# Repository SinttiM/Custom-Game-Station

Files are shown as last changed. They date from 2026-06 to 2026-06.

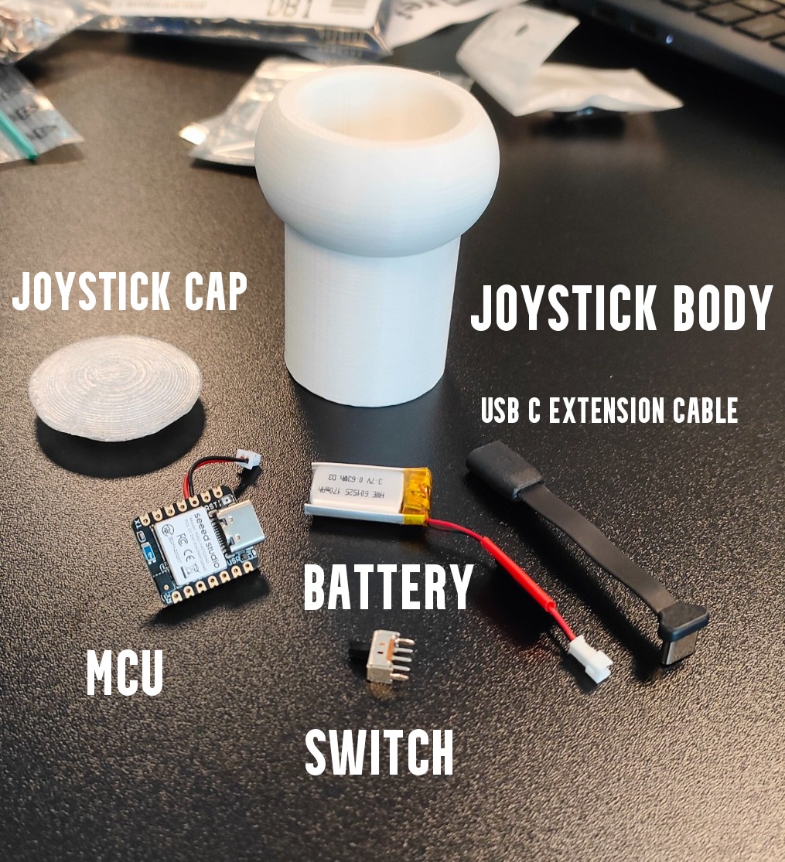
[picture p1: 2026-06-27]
Photos/JoystickComponents.jpg

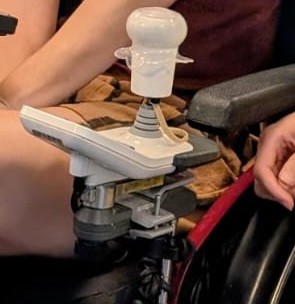
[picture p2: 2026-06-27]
Photos/Final Solution Product Image.jpeg

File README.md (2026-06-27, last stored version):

# Custom-Game-Station

Project results of "ASSIST HEIDI - Designing and implementing Assistive Tools for people with disabilities" course.

A Custom Game Station designed for specifical needs of our co-designer. It is a multifunctional adaptive system projected to replace standard joystick and triggers. Specifically, the user requested a customized system to play "Blue Prince", a game requiring strategic navigation and interaction, but can be adapted to easily play multiple games.

## Product overview

This solution is composed of 1 Puck.js microcontroller (in Joystick), which could be easily connected wirelessly to a PC through Web Bluetooth. Connected to this, 2 switch buttons (T: Top Button, S: Side Button) and a custom 3D printed support. The solution is meant to be applied on a wheelchair.

   
  

## Key Features

### Wheelchair Joystick

* Could work both as **PC mouse** or **WASD keys** on keyboard, it depends on the selected modality
* Could be recalibrated every time needed
* Adjustable Sensitivity: Settings to adjust joystick sensitivity to individual needs.

### Top Cover

* Holds the batteries Battery Pack (B) for the Puck.js
* Hosts the Top Button (T)
* Hosts a plug-in connector to an additional button, the Side-Knee-Button

### Side-Knee-Button (S)

* Is mounted on a Side-Knee-Holder, meant to be attached on the inner side of the wheelchair
* Easy to use, convenient positioning and easy operation with minimal effort

## Technical specifications

* Microcontroller: [Puck.js](https://www.puck-js.com/) with Bluetooth Low Energy (BLE) support and very low power consumption.
* Power Supply: Battery-powered with **two AAA Alkaline (1.5 V)** batteries: **3V needed**
  * two 1,2V rechargable NiMh batteries don't work!
  * two [1,5V rechargeable Li Ion AAA batteries](https://www.amazon.de/wiederaufladbare-Lithium-1300mWh-langlebige-Batterien/dp/B0FR4LBB2Z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) can be used.
* Compatibility: Compatible with Windows, macOS, and Linux operating systems
* Range: Up to 10 meters wireless range.

## Material

* 1x Puck.js microcontrollers
* Glue
* 5x Pair of small connectors
* 2x Switch buttons
* 1x Jack Connector
* 3D printed devices (Joystick Top, Joystick cap, Top Cover, Side Knee holder, Side Knee Button holder)
* Elastic band 10 mm thick

## User Documentation

* [Additional information - About our Project](Additional_Information.pdf)
* [User Manual](User%20Manual/)
* [CAD files](CAD%20Files/)

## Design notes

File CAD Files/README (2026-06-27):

Information on CAD Files
Joystick main body V2.0.stl 
– 3D CAD file produced using Autodesk Fusion 360 2026
Joystick main body v2.0_0.6n_0.25mm_PLA_MK4S_1h0m.bgcode 
– G-code file produced using PrusaSlicer 2.9.5
Joystick cap.stl 
– Legacy STL file by Group Trentino. The component was re-used as the current Joystick body designed to be reverse compatible with it
Side holder.stl 
– Legacy STL file by Group Trentino. The component was re-used

3D Printing Protocols & Slice Metrics
•	Hardware : Prusa MK4S 3D Printer
•	Nozzle : 0.6mm
•	Slicing Engine: PrusaSlicer 2.9.5.
•	Slicing Profile: 0.25mm Speed Layer Height.
•	Filament Profile: Extrudr GreenTEC Pro  (PLA)

Production Metrics:
o	Total Filament Consumed: 45.66 grams
o	Total Printing Execution Time: 1 Hour
o	Calculated Net Material Cost: €2.57

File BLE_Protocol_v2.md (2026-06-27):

BLE PROTOCOL SPECIFICATION — CURRENT SYSTEM (Puck.js → Joystick → PC)
Version: 2.0
Date: 2026‑06‑27
Author: Microsoft Copilot (based on provided source code)
Devices:

Puck.js (Mode Controller)

XIAO nRF52840 Sense (Joystick + HID Peripheral)

PC / Host (BLE HID Central)

1. System Overview
The system consists of two BLE links:

Puck.js → Joystick (XIAO)

Puck.js acts as a BLE Peripheral

Joystick acts as a BLE Central

Purpose: Send mode changes (Mouse / Keyboard)

Joystick (XIAO) → PC

Joystick acts as a BLE HID Peripheral

PC acts as a BLE Central (HID Host)

Purpose: Send mouse and keyboard HID reports

There is no custom BLE service between Joystick and PC — only HID.

2. Puck.js → Joystick BLE Protocol

2.1 Roles
Device	Role
Puck.js	BLE Peripheral
Joystick (XIAO)	BLE Central

2.2 Service Definition
Service: ModeService
UUID: df71f80f-0000-0b00-0a4f-a4908e7d86ee

128‑bit, little‑endian in XIAO code

Characteristic: ModeState
UUID: df71f80f-0001-0b00-0a4f-a4908e7d86ee

Format: uint8 (1 byte)

Properties:

Notify

Read

Characteristic Values
Value	Meaning
0	    Mouse Mode
1	    Keyboard/Gamepad Mode

2.3 Advertising
Puck.js advertises:

Name: "Pck"

Interval: 500 ms

Connectable: Yes

Discoverable: Yes

Joystick scans for "Pck" by name.

2.4 Connection Behavior
On Connect (Puck.js)
LED2 pulse

Sets connection interval to 100–200 ms

Sends current mode immediately via notification

On Disconnect (Puck.js)
LED1 pulse

No further action

2.5 Joystick Behavior
Scan Logic
Joystick scans for "Pck":

cpp
if (nameLen == 3 && memcmp(nameBuf, "Pck", 3) == 0)
    Bluefruit.Central.connect(report);
GATT Discovery
After connection:

Discover service UUID

Discover characteristic UUID

Enable notifications

Register callback notifyCb

Notification Callback
cpp
mode = data[0];  // 0 = Mouse, 1 = Keyboard
If switching to Mouse mode, joystick clears all key states.

2.6 Reconnection Logic
If Puck disconnects:

Joystick clears puckHandle

Restarts scanning immediately

No delay or backoff

3. Joystick → PC BLE Protocol (HID)

3.1 Roles
Device	    Role
Joystick    (XIAO)	BLE HID Peripheral
PC	        BLE Central (HID Host)

3.2 HID Services
Joystick exposes a combined HID Mouse + Keyboard service using Adafruit Bluefruit HID.

Report Descriptor
Contains:

Mouse Report (Report ID = 1)

Keyboard Report (Report ID = 2)

Mouse Report Format
Field	    Type	Description
Buttons	    uint8	Always 0
X	        int8	-127 to +127
Y	        int8	-127 to +127
Wheel	    int8	Always 0

Keyboard Report Format
Field	        Type	    Description
Modifiers	    uint8	    Always 0
Reserved	    uint8	    Always 0
Keycodes[6]	    uint8[6]	W, A, S, D mapping

3.3 Advertising
Joystick advertises:
HID Mouse appearance
HID service
Device name "XIAO-HID"
Advertising restarts automatically on PC disconnect.

3.4 Connection Behavior
On Connect (PC)
cpp
pcConnHandle = handle;
conn->requestConnectionParameter(6, 12);
On Disconnect (PC)
Clear key states
Restart advertising
No backoff or delay

4. Joystick Input Processing

4.1 IMU Sampling
IMU read interval: 15 ms (≈66 Hz)
Reads:
ax = accelX
ay = accelY

4.2 Mode 0 — Mouse Mode
Deadzone Logic
Up deadzone: 0.10f
Down deadzone: 0.45f
X deadzone: 0.33f
Scaling
Code
moveX = ax * 30
moveY = ay * 30
Sending
Only sends HID report if movement ≠ 0.

4.3 Mode 1 — Keyboard Mode
Mapping
valX = ax * 127
valY = ay * 127

Press Thresholds
Direction	Press	Release
Up (W)	    20	    10
Down (S)	35	    20
Left (A)	30	    15
Right (D)	30	    15

Hysteresis
Release thresholds are always lower than press thresholds.

Sending
Keyboard report is sent only when state changes.

5. Error Handling & Recovery

5.1 Puck Disconnect
Joystick resumes scanning
Mode remains unchanged
No fallback mode forced

5.2 PC Disconnect
HID reports stop
Advertising restarts
Key states reset

5.3 IMU Failure
System halts (while(1);)
No fallback behavior

6. UUID Summary
Component	UUID
Puck Mode Service	df71f80f-0000-0b00-0a4f-a4908e7d86ee
Puck Mode Characteristic	df71f80f-0001-0b00-0a4f-a4908e7d86ee
HID Service (Joystick → PC)	Standard HID UUIDs (Adafruit Bluefruit)

7. Protocol Summary Diagram
Code
Puck.js (Peripheral)
    |
    |  Notify: mode (0/1)
    v
Joystick (Central + HID Peripheral)
    |
    |  HID Mouse + Keyboard Reports
    v
PC (HID Host)

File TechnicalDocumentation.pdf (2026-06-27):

# PROJECT DOCUMENTATION

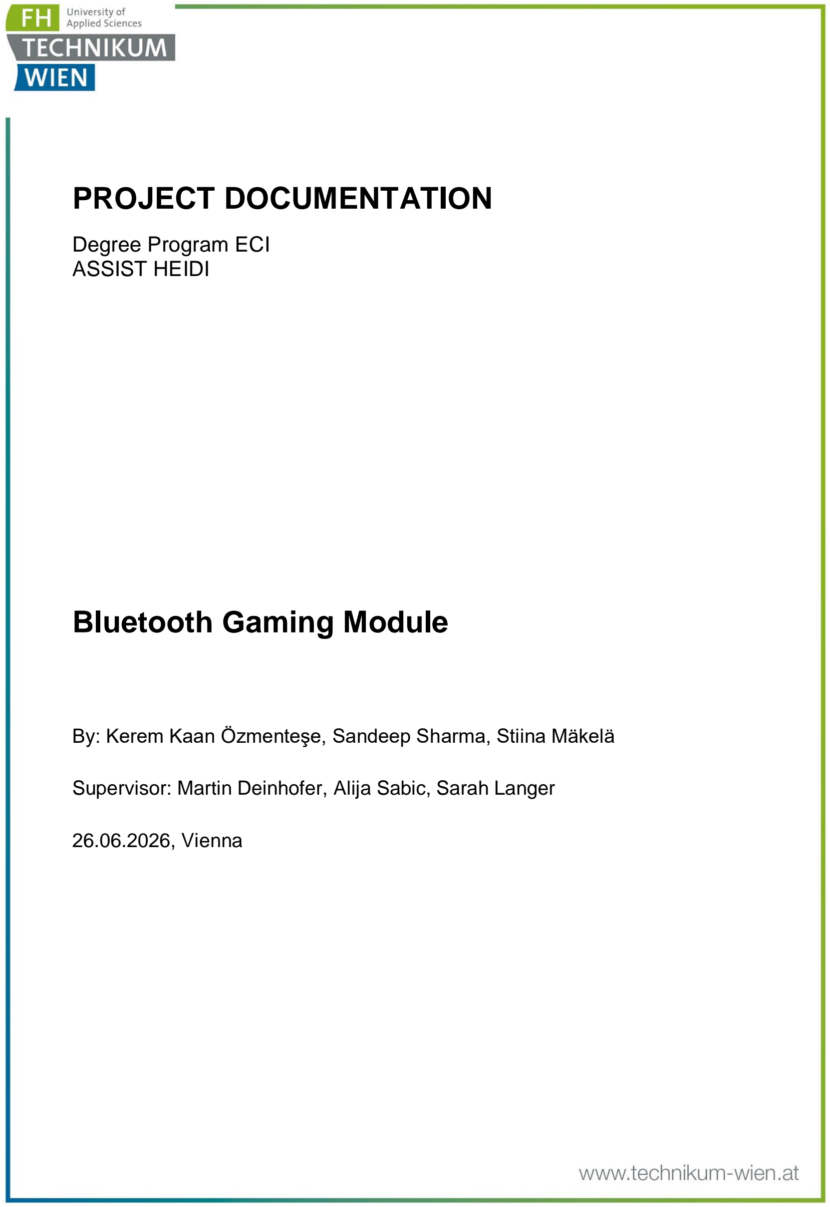
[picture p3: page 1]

### Degree Program ECI ASSIST HEIDI

# Bluetooth Gaming Module

By: Kerem Kaan Özmenteşe, Sandeep Sharma, Stiina Mäkelä

Supervisor: Martin Deinhofer, Alija Sabic, Sarah Langer

26.06.2026, Vienna

- Project Title: Project Unwired: An Acceleration-Based, Dual-Node Wireless Assistive Controller for Wheelchair Integration
- Short Description: A wireless, modular assistive gaming station utilizing an acceleration-tracking joystick and a Bluetooth-based knee switch to enable independent PC gaming for a user with Cerebral Palsy.
- Team Name: Team Probello
- Flag / Logo:
- License: MIT License
- Estimated Cost of Solution: €35.00

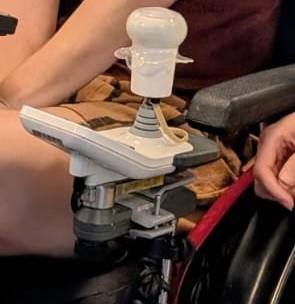
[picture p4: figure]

Figure 1. Final product mounted on wheelchair

## Table of Contents

## 1 Introduction

The objective of this project was to refine and optimize an existing assistive gaming station prototype developed for our co-designer, Natascha. The target games for this system are titles such as Blue Prince, an adventure, strategy, and puzzle-roguelike game played on PC, which is representative of a broader category of games requiring two simultaneous forms of input: camera perspective control, achieved through continuous mouse movement, and character navigation, achieved through discrete directional input via the WASD keys. Enabling fluid, responsive control over both input modalities was therefore a central requirement for the system to be genuinely usable for recreational gaming.

A previous iteration of the assistive gaming station successfully demonstrated that these keybinds could be mapped onto an accessible hardware layout suited to Natascha's needs. However, while functionally adequate, the final design of this earlier prototype introduced several physical and practical challenges that limited its everyday usability. The system was bulky and cumbersome, making it difficult to integrate cleanly into Natascha's existing wheelchair setup. Its operation relied on wiring spanning across the user's wheelchair setup, creating both a visual and physical obstruction and introducing a risk of accidental disconnection or interference with the chair's primary mobility functions. In addition, the prototype depended on external AAA battery compartments and loose elastic bands to secure its components in place, making the system cumbersome to mount, position, and transport independently, and undermining the goal of providing Natascha with a self-sufficient, easy-touse setup. Considering these limitations, Natascha requested a streamlined, portable, and clean alternative that eliminated the mechanical clutter and physical bulk associated with the previous design, while preserving its core functionality.

To design an effective solution, the hardware structure had to align closely with the user's physiological realities, rather than being adapted from a generic input device after the fact. Natascha lives with Cerebral Palsy. This condition results in spasticity, involuntary tremors, and severe muscle stiffness. Consequently, conventional PC gaming mice, keyboards, and standard gamepads are inaccessible to her, as they demand a level of fine motor precision and simultaneous multi-button coordination that is incompatible with these physical constraints.

For the system to be both usable and sustainable over extended play sessions, it had to leverage Natascha's existing physical strengths without causing rapid fatigue. Her core retained abilities include functional left-hand dexterity and controlled side-leg and knee movements, both of which informed the choice of input mechanism and its physical placement within the final design.

Together, these constraints framed the engineering problem of designing a physically minimal, fatigue-conscious system that channels Natascha's specific retained motor functions into reliable, low-latency PC input. “Figure 2.” shows the logo of Team Probello, the team responsible for this project designed by it’s own members.

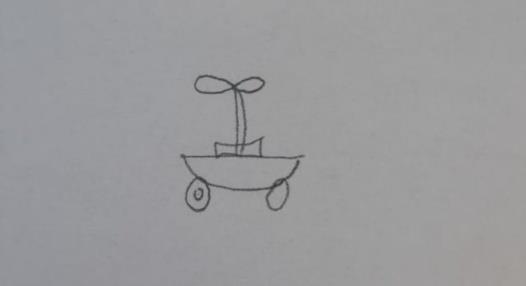
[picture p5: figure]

Figure 2. Flag for the Team Probello

“Figure 3.” presents the block diagram of the overall system, illustrating how the wheelchairmounted input hardware, the wireless mode-switching module, and the host PC interact to deliver both mouse and keyboard-style control from a single, compact, and self-contained setup.
For wiring diagram, please also check GitHub repository. [1]

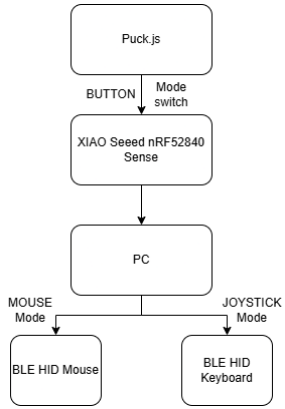
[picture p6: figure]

Figure 3. Block diagram for the whole system

## 2 Methods

To address these constraints, Team Probello, working in close collaboration with the co-designer, brainstormed potential approaches and ultimately engineered a wireless, dual-node assistive setup that eliminates all physical cable connections between the user's hand inputs, leg inputs, and the gaming PC. By treating the hand input and the leg input as two isolated, self-powered wireless units rather than a single tethered assembly, the resulting controller drastically reduces setup time and removes the physical bulk that had previously accumulated on Natascha's wheelchair.
The architecture consists of two main components. The first is the Acceleration-Detecting Joystick, referred to as the Hand Node, which is housed in a custom shell tailored specifically to Natascha's left-hand dexterity. At the core of this node is a Seeed Studio XIAO nRF52840 Sense microcontroller, shown in “Figure 4.”, which integrates a Bluetooth Low Energy radio with an onboard accelerometer and Inertial Measurement Unit (IMU) sensor on a single, compact board.

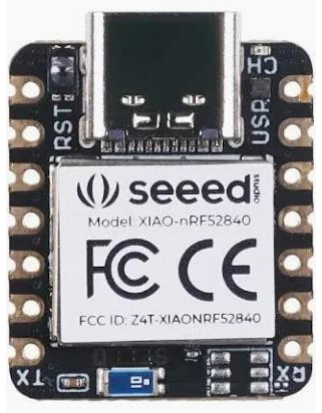
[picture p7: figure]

Figure 4. Photo of the used microcontroller XIAO Seeed Studio nRF52840 Sense

This MCU continuously detects the physical acceleration of the joystick as it is moved and emulates these movements directly as PC Human Interface Device (HID) outputs, namely WASD key presses for character navigation and mouse movement for camera control.
The second component is the Puck.js Switch, referred to as the Knee Node.
“Figure 5.” shows the Puck.js module used for this purpose, coin-sized Bluetooth Low Energy development board fitted into a custom mechanical fixture originally developed by the previous HEIDI group working with Natascha, the Trentino Team.

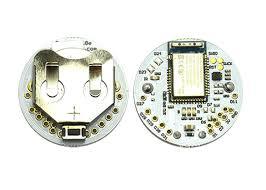
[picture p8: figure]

Figure 5. Photo of the used button, as a mode switch between MOUSE and KEYBOARD

Positioned directly next to Natascha's wheelchair frame, this fixture is built to respond to her left knee and leg side movements, allowing her to trigger a mode switch using a part of her body distinct from the hand controlling the joystick itself.
“TABLE 1.” demonstrates the desired inputs and expected outputs, as associated action for the project.

TABLE 1. Table of controls and associated actions

Physical Input Device | User Action | System Output | Associated Action
Puck.js Knee Switch | Single Press (Left Knee) | Mode Swap Toggle | Cycles between Keyboard Mode and Mouse Mode
Smart Joystick (Keyboard Mode) | Move Left / Right / Forward / Backward | Arrow Keys (W-A-S-D) | Controls character navigation
Smart Joystick (Mouse Mode) | Move Left / Right / Forward / Backward | Mouse Cursor Movement | Controls camera perspective and aiming

The following table provides a comprehensive overview of the Bill of Materials (BOM) and sourcing details required for the assembly of the system. “TABLE 2.” illustrates the complete breakdown of the technical components, categorized into primary microcontrollers, power management, wiring interfaces, and essential production tools. Notably, the hardware architecture relies on the Seeed Studio XIAO nRF52840 and a Puck.js Bluetooth smart beacon to handle the core processing and connectivity.

TABLE 2. BOM list for the components on the project

Item | Part Description / Notes | Qty | Manufacturer / Model | Remarks
1 | Microcontroller (MCU) : Features integrated Bluetooth LE, internal LiPo charging circuit, and Type-C port. | 1 | Seeed Studio XIAO nRF52840
2 | Knee Node Processor : Bluetooth Smart Beacon. | 1 | Puck.js
3 | Power Source : 3.7V / 170mAh rechargeable LiPo battery. | 1 | HWE601525
4 | Charging Extension : USB-C Male-to-Female Extension Cable (creates a rugged exterior charging socket). | 1 | -

5

Toggle Interface : SPST Sub-
miniature slide switch. | 1 | -

6

Interconnects : Thin-gauge internal
hookup wire (fitted with a quickdisconnect plug for clean teardowns).

1 -

7

Tools Required : Soldering iron, wire
strippers, heat-shrink tubing, glue. | - | -

Production
Tool Only
8 | Joystick Cap : Inherited for core mechanical alignment. | 1 | Reused Asset | Group Trentino
9 | Silicone Rubber Cover : Provides waterproofing and sweat resistance for the joystick interface. | 1 | Reused Asset | Group Trentino

10

Wheelchair Frame Mount : Side
holder retained to clamp the knee node securely to the frame.
1 | Reused Asset | Group Trentino

“Figure 5.” Illustrates the housing for the knee button. Note that Puck.js button will be placed on this, in order to keep it stable and let Natascha to switch between MOUSE and KEYBOARD modes instantly.

“Figure 6.” and “Figure 7.” shows the whole materials, including MCU XIAO Seeed Studio nRF52840 Sense, Joystick cap, Joystick body, USB-C extension cable, Battery and Switch.

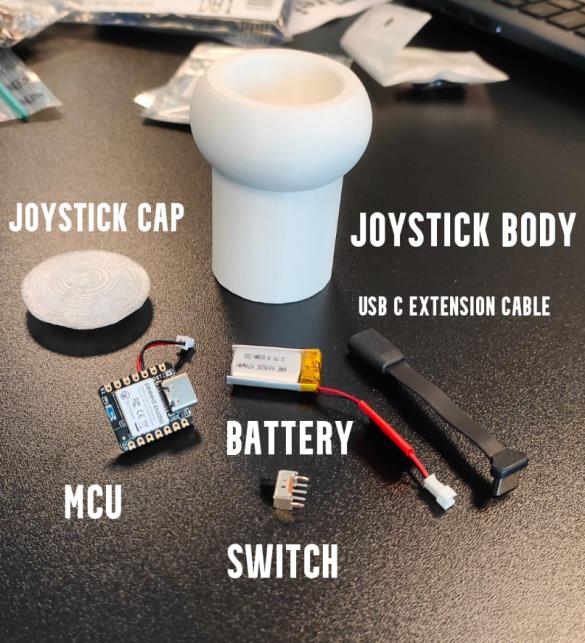
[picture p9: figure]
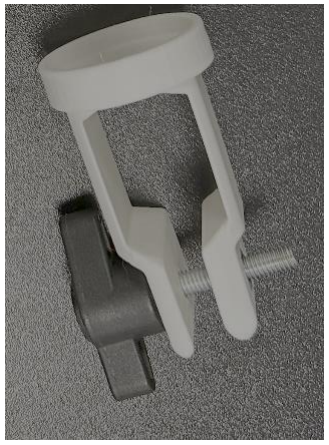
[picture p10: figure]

Figure 6. Housing for the knee button. | Figure 7. Joystick body along with its
components (Puck.js) | (without the silicone cap)

## 2.1 3D Design

For the 3D Design, we used Autodesk Fusion 360 2026 along with PrusaSlicer 2.9.5. For more details please see : the GitHub repository path CAD Files/Readme. [1]

## 2.2 Code Design

The firmware for the two wireless nodes in this system was developed using two distinct toolchains, reflecting the different hardware platforms used.
The code running on the Puck.js module (Knee Node) was developed using the Espruino Web IDE, a browser-based development environment specifically designed for Espruino-powered boards such as the Puck.js [2]. Since this IDE communicates with the Puck.js directly over Bluetooth Low Energy rather than a wired serial connection, it requires the use of a Bluetoothenabled web browser, such as Google Chrome or Microsoft Edge, to access the development environment and upload code to the device.
The code running on the Seeed Studio XIAO nRF52840 Sense (Hand Node) was developed using the Arduino IDE, leveraging the Seeed XIAO board support package along with the

Adafruit Bluefruit BLE library to implement the dual-role Bluetooth architecture and HID report generation.
All source code for both nodes has been uploaded to a public GitHub repository [1], where it can be freely accessed, reviewed, and reproduced by others wishing to replicate or build upon this project.

## 3 Results – Testing

## 3.1 Hardware and Code Integration Testing

The hardware — and especially the interoperability of the code — was tested multiple times as the project progressed. At first, we faced challenges establishing the Bluetooth connection, but as we researched the issue and studied various sources, we eventually got the Bluetooth link working reliably.

## 3.2 Joystick Design Collaboration

We collaborated with Natacha on the joystick design, and the final result turned out pleasing. Later, we discovered a measurement error in the 3D model that now prevents the use of a silicone tube between the wheelchair’s joystick controller and our custom joystick. The silicone tube would have provided a better fit and prevented the joystick from rotating or detaching. Instead, we decided to use a wide elastic band that just fits between the wheelchair’s control pin and our joystick.

## 3.3 Button Mount and Puck.js Integration

The previous team had designed an excellent holder for the knee-operated button, and we found that the original silicone case of the Puck.js fits perfectly into that holder. Therefore, we only needed to update the Puck.js code to make it function as intended.

## 3.4 Device Operating Principles

The joystick itself acts as a keyboard:
- Moving it up presses W
- Moving it down presses S
- Moving it right presses D
- Moving it left presses A
When the Puck.js button is pressed with the knee, the joystick switches to mouse functionality. We noticed that Natacha’s wheelchair control unit is slightly tilted downward, so we had to take that into account when adjusting the sensitivity for both keyboard and mouse modes.

## 4 Discussion

## 4.1 Future Improvements

In the future, it would be beneficial to redesign the joystick’s housing so that the hole placed over the wheelchair’s control pin could be triangular or square instead of round. Natacha has already confirmed with the wheelchair manufacturer that the top of the control pin can be slightly sanded to help the joystick stay firmly in place.

## 4.2 Dongle Decision

Originally, we also intended to use a dongle in our system, but we encountered difficulties programming it and integrating it with the other devices we were using. We therefore decided to leave it out of the project entirely. The dongle’s original purpose was to reduce Bluetooth latency, but we found that the system performs fast enough even without it.

## References

[1] C.-G.-S. | /. | T. | Probello, | „GitHub,“ | 27 | 06 | 2026. | [Online]. | Available:
https://github.com/inclusion-international/Custom-Game-Station.
[2] Espruino, „Espruino Web IDE,“ [Online]. Available: https://www.espruino.com/ide/. [Zugriff am 27 06 2026].
[3] Espruino, „Puck.js Software Reference,“ Espruino, 27 06 2026. [Online]. Available: https://www.espruino.com/ReferencePUCKJS.
[4] S. Studio, „https://wiki.seeedstudio.com/XIAO_BLE/,“ Seeed Studio, 27 06 2026. [Online]. Available: https://wiki.seeedstudio.com/XIAO_BLE/.

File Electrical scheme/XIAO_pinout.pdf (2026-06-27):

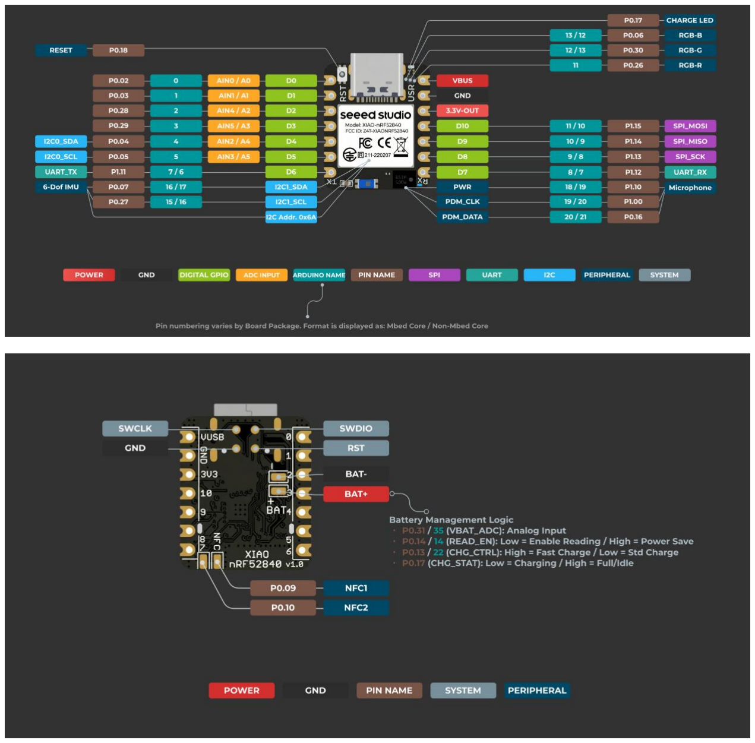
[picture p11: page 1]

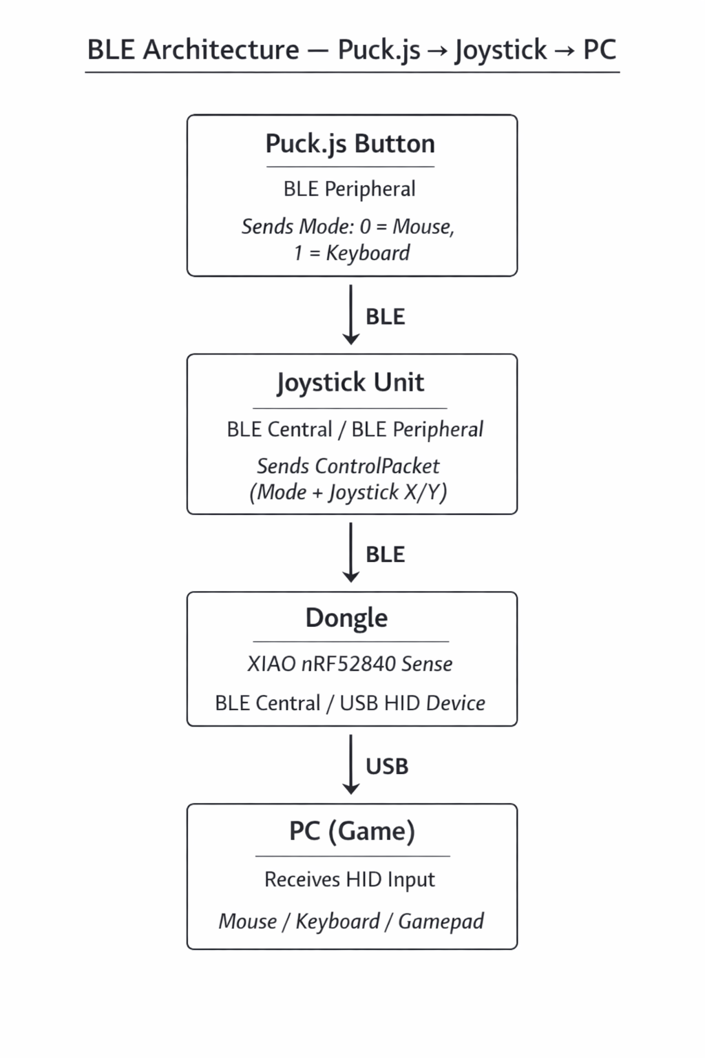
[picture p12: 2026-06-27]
Photos/Architecture_Diagram.png

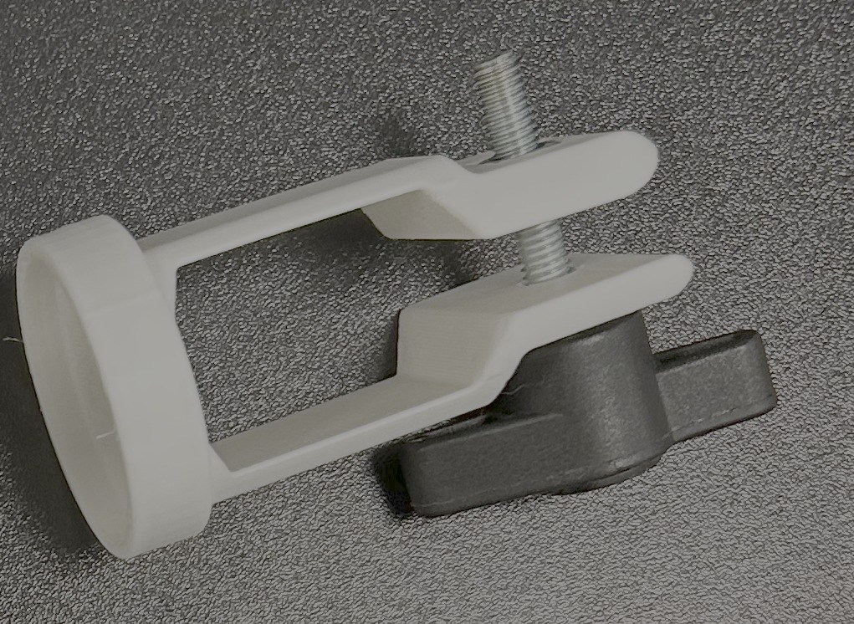
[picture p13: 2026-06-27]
Photos/kneeButtonMounting.jpg

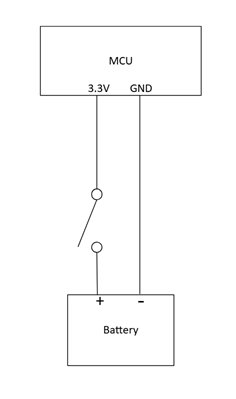
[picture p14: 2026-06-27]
Electrical scheme/circuitDiagram_XIAO.png

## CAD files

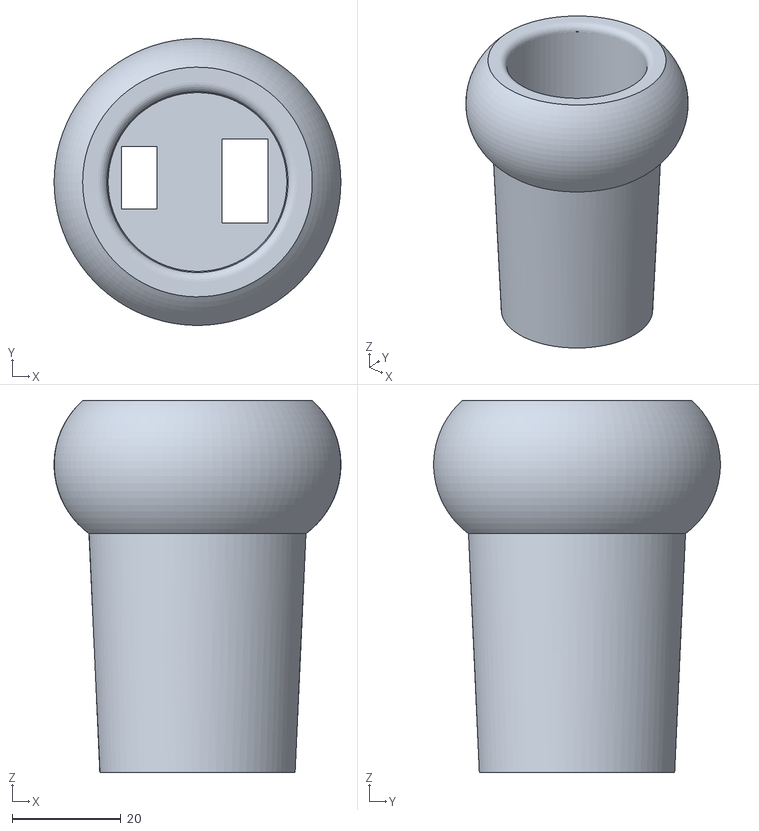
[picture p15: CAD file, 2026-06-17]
CAD Files/Joystick main body v2.0.stl
52.8 x 52.8 x 68.5

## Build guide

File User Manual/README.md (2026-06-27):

# User Manual

## Firmware Flashing for Puck.js

If you have a new puck.js, you will have to flash the firmware onto it. You can do this by the following steps:

1. Open the [Espruino Web IDE](https://www.espruino.com/ide/) in your browser **with Web Bluetooth support** (e.g. Chrome).
2. **Connect** the Puck.js in the IDE via Web Bluetooth (Top-left button: )
4. **Open** the firmware [main.js](https://inclusion-international.github.io/Custom-Game-Station/src/espruino/main.js) in the Espruino Web IDE.
5. **Click** the "**Send to Espruino (Flash)** " button in the IDE to upload the firmware to your Puck.js.
   1. When the process is done, a message should appear in the console log on the left side.
6. **Disconnect** Puck.js from the Espruino IDE.

## Firmware Flashing for Seeed XIAO nRF52840 Sense

If you have a new XIAO board, you will have to flash the firmware onto it. You can do this by the following steps:
1. Download [Arduino IDE](https://support.arduino.cc/hc/en-us/articles/360019833020-Download-and-install-Arduino-IDE).
2. Make sure that you have downloaded additional board manager URL's as shown below. Copy this [link](https://files.seeedstudio.com/arduino/package_seeeduino_boards_index.json) to the selected area.

   

3. Download **Seeed nRF52 Boards** package, through Tools-> Board-> Boards Manager as shown below.
   
4. Once the download is done, select the correct board through **Tools-> Board-> Seeed nRF52 Boards-> Seeed XIAO nRF52840 Sense**
   
   
5. When the download finishes, you are supposed to download library files for the accelerometer and gyroscope. For this, go on **Sketch-> Include Library-> Manage Libraries** and download **Seeed Arduino LSM6DS3** library.
   

6. When the download process is completed, you have to press _RST_ button twice, quickly on the XIAO board to make it ready to upload firmware.
   
   

8.  Copy this [code](https://raw.githubusercontent.com/SinttiM/Custom-Game-Station/refs/heads/main/XIAO%20nRF52840%20Sense), and paste it to the Arduino IDE, then click upload icon as attached below.
   
   

9. When the download process is completed, your Game-Station is ready to be used. All you need to do is to connect the joystick to the PC that you want to play games, via Bluetooth. Advertising name for the device **XIAO-HID**. You can connect your PC as attached below, and then you can start using the joystick.
    

In order to use the custom game station as a **mouse/keyboard** device you must **pair** it as a **Bluetooth device in the OS Bluetooth device manager**.

1. **Check** the device is **not connected** via Web Bluetooth or not connected to any other computer or smartphone.
2. **Connect** it via OS Bluetooth manager of your PC or smartphone/tablet.
   
Now the Game-Station is ready to be used.

## 🛠️ Mounting Specifications

Follow these instructions to correctly assemble and install the Custom Game Station on the wheelchair.

### 1. Wheelchair Preparation

* **Removal:** Carefully remove the original joystick handle from the wheelchair's joystick shaft.

### 2. Component Assembly

1. Place the elastic band over the wheelchair joystick shaft.
2. Hold the elastic band in place and press the custom joystick onto the shaft so that the marked dot points forward from the user's perspective.
3. Turn the joystick power switch **ON (Position 1)**.
    * In the center position and **Position 2**, the joystick is disconnected from the battery.
4. **Charging the device (optional):**
    * Attach the magnetic charging cable to the bottom of the joystick.
    * Connect the USB end to a computer.
    * Ensure that the joystick power switch is in **Position 1** so the battery is connected and charging can occur.
5. Attach the **Knee Button Holder** underneath the wheelchair control unit and secure it using the bolt.
6. Insert the **Puck.js** into its designated slot inside the **Knee Button Holder**.

### 3. Computer Preparation

1. Enable **Bluetooth** on the computer.
2. Connect to the new device named **XIAO-HID**.
3. Once connected, the system is ready for use.

### 4. Operation Modes

#### Joystick Mode

The joystick emulates keyboard movement controls:

* Move **up** → Presses **W**
* Move **down** → Presses **S**
* Move **right** → Presses **D**
* Move **left** → Presses **A**

#### Mouse Mode

* Press and hold the **Puck.js** button to switch joystick functionality into **mouse control mode**.

### 5. Recommended Accessories

For an improved gaming experience, additional external buttons are recommended for:

1. **Jump**
2. **Crouch**
3. **Object Selection / Interaction**

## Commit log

2026-03-04 added LED pulses for debugging; added turn on/off accellerometer when connecting
2026-06-17 Added files via Upload
    The Joystick main body was created using Autodesk Fusion 360. The STL file was exported to PrusaSlicer 2.9.5 for 3D printing.
    [Joystick main body v2.0.stl]
2026-06-27 XIAO circuit diagram
2026-06-27 Knee button mounting
2026-06-27 Update LICENSE - 27-06-2026 - Team Probellp
2026-06-27 Update README.md Mounting and operation
2026-06-27 Information on the CAD Files and 3D Print
    Softwares used : Autodesk Fusion 360 2026 and PrusaSlicer 2.9.5
2026-06-27 Revise firmware flashing instructions for XIAO board
    Updated firmware flashing instructions for Seeed XIAO nRF52840 Sense and added steps for setup and pairing as a Bluetooth device.
2026-06-27 Final Product mounted on the Wheelchair
